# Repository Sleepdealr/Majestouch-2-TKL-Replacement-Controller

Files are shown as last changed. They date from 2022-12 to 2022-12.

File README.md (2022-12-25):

# Majestouch 2 TKL Replacement Controller

This board has been prototyped. It is tested and working

Kicad source files are provided, as well as QMK firmware with Vial support

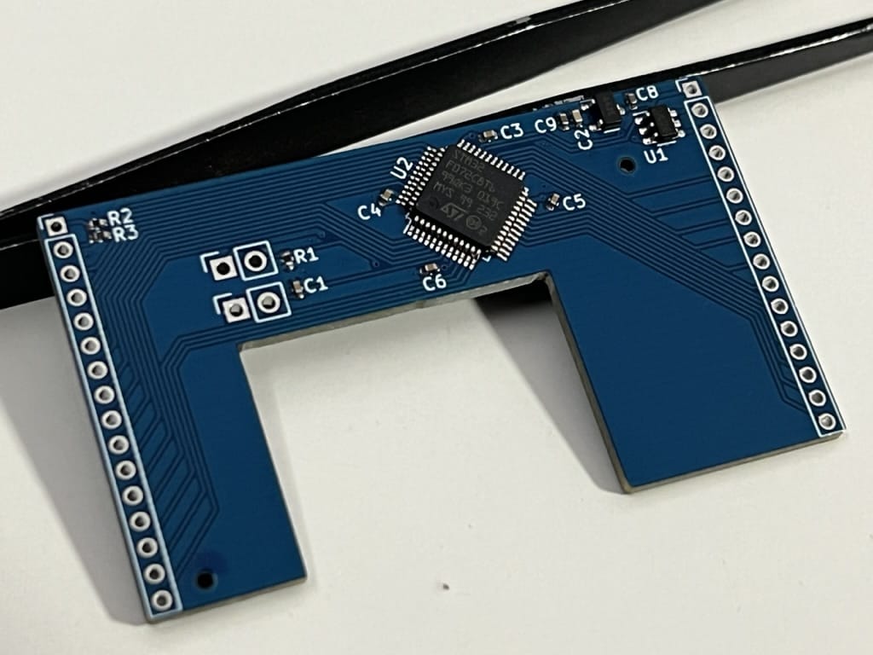
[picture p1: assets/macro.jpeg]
Macro Photo

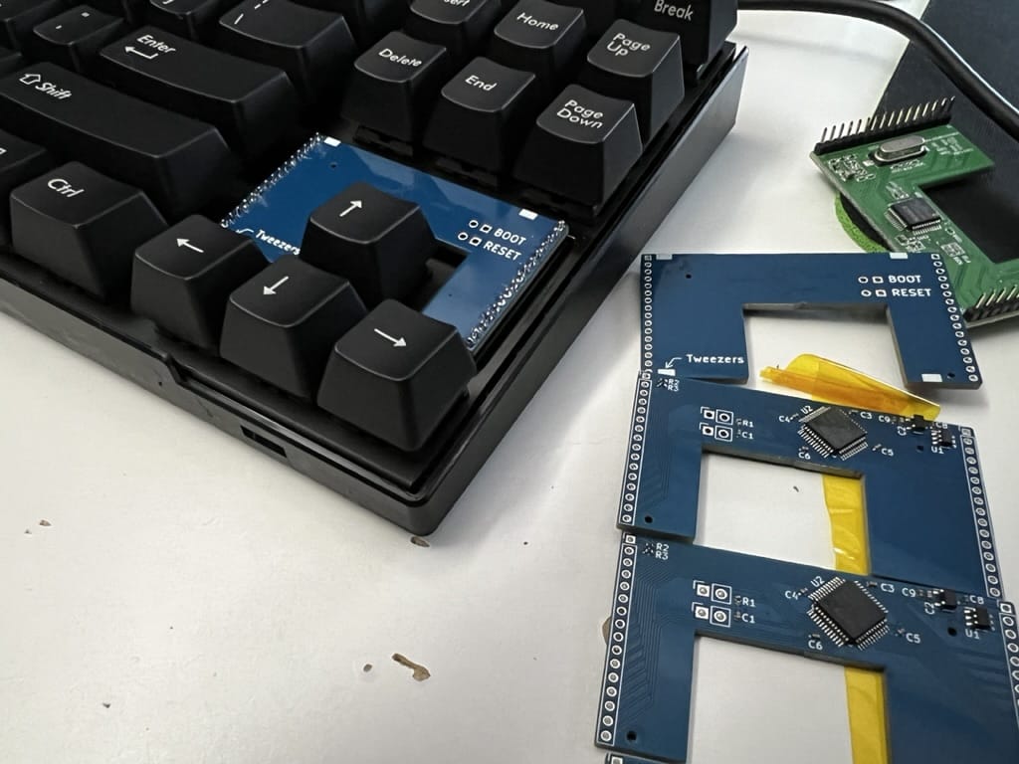
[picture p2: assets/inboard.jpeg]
In Board


## Resources Used

- Matrix: <https://deskthority.net/wiki/Controller_matrix_traces#Filco_Majestouch_TKL>
- Outline: <https://github.com/Tecsmith/flying-horse-foot/>
  - Used calipers to double check with physical model

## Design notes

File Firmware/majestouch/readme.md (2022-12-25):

# Majestouch 2 TKL Replacement Controller

Replacement controller for the Majestouch 2 TKL

* Keyboard Maintainer: [Sleepdealer](https://github.com/Sleepdealr)
* Hardware Supported: Majestouch 2 TKL
* Hardware Availability: Amazon or whatever

Make example for this keyboard (after setting up your build environment):

    make sleepdealer/majestouch:default

Flashing example for this keyboard:

    make sleepdealer/majestouch:default:flash

See the [build environment setup](https://docs.qmk.fm/#/getting_started_build_tools) and the [make instructions](https://docs.qmk.fm/#/getting_started_make_guide) for more information. Brand new to QMK? Start with our [Complete Newbs Guide](https://docs.qmk.fm/#/newbs).

## Bootloader

Enter the bootloader in 3 ways:

* **Bootmagic reset**: Hold down the key at (0,0) in the matrix (usually the top left key or Escape) and plug in the keyboard
* **Physical reset button**: Briefly press the button on the back of the PCB - some may have pads you must short instead
* **Keycode in layout**: Press the key mapped to `RESET` if it is available

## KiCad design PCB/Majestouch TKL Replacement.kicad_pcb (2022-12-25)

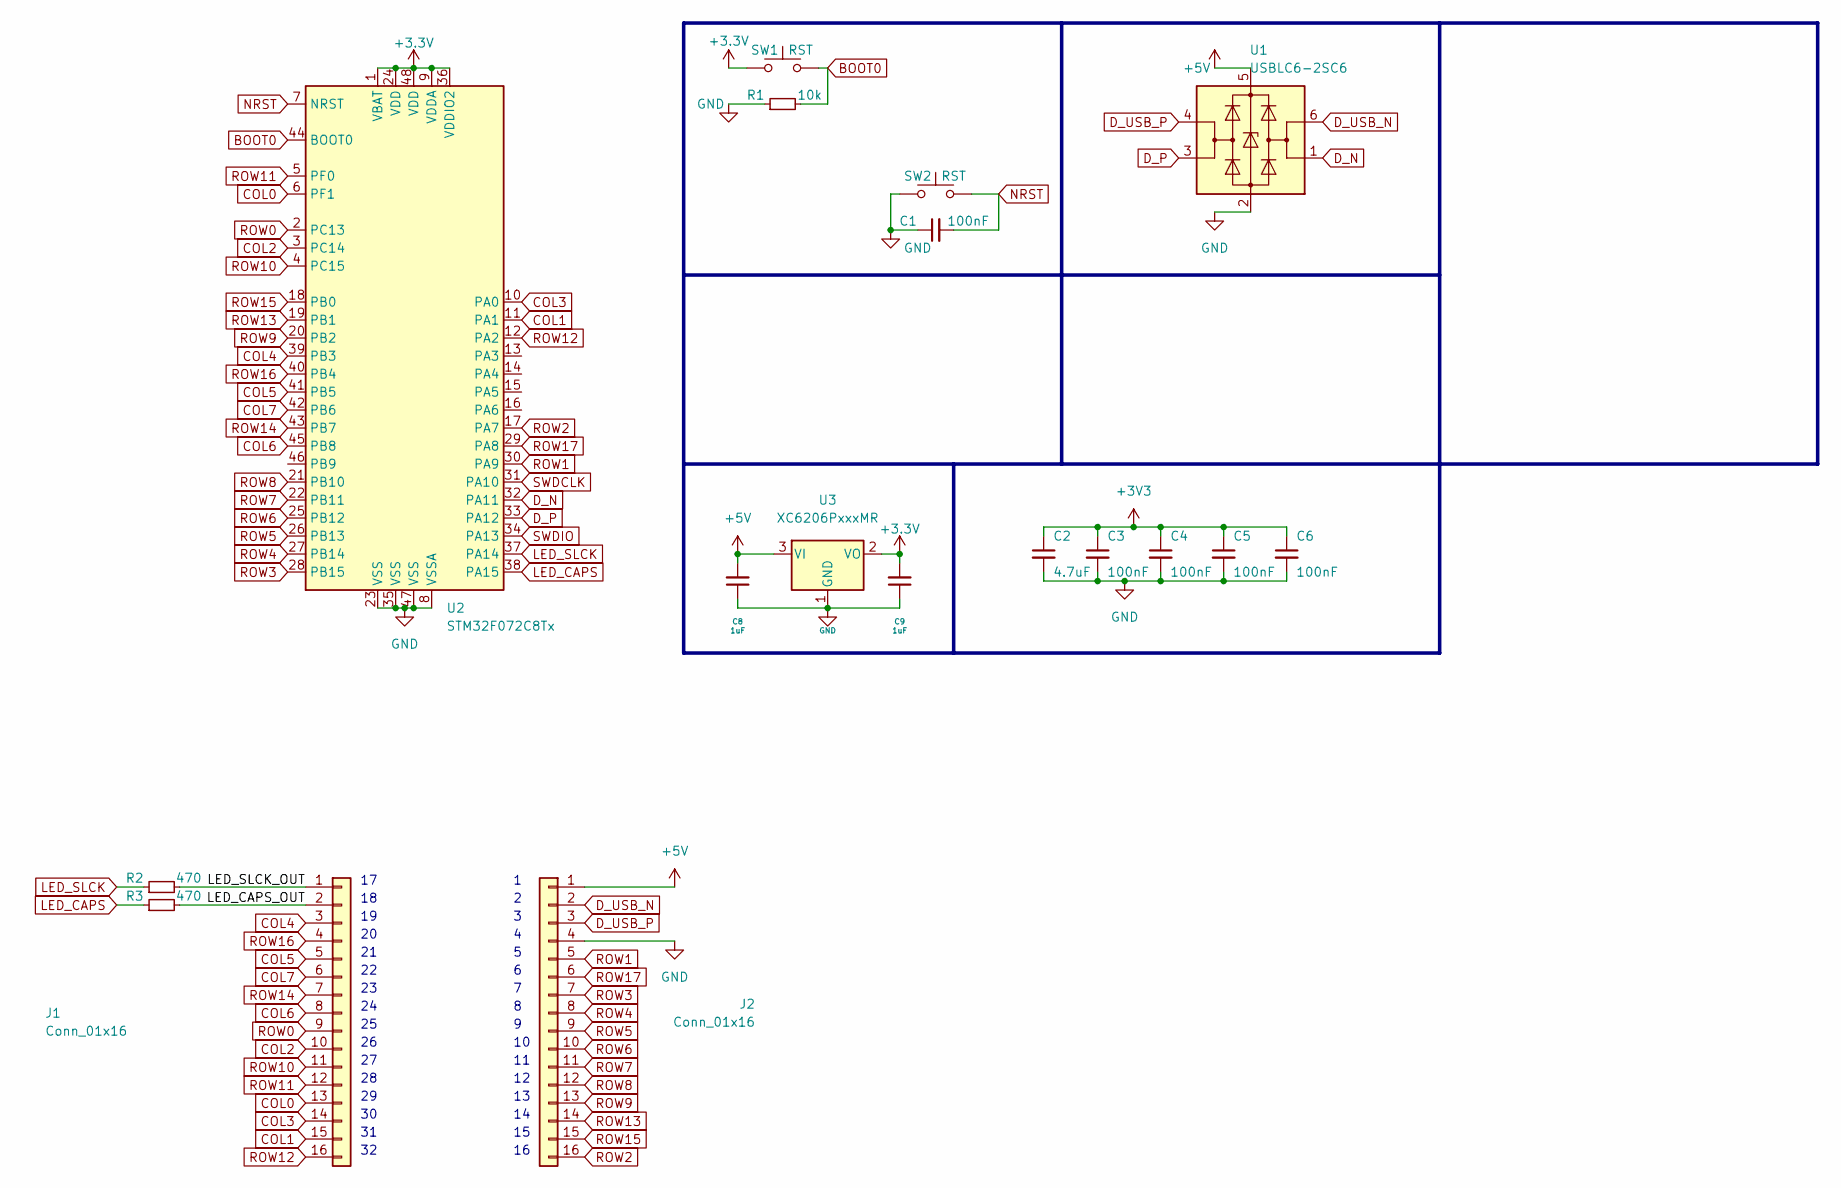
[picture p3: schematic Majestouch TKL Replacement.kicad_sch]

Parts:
C1, C3, C4, C5, C6: 100nF; C_0402_1005Metric; LCSC C307331
C2: 4.7uF; C_0402_1005Metric; LCSC C52923
C8, C9: 1uF; C_0402_1005Metric; LCSC C52923
J1, J2: Conn_01x16; PinHeader_1x16_P2.00mm_Vertical
R1: 10k; R_0402_1005Metric
R2, R3: 470; R_0402_1005Metric
SW1, SW2: RST; PinSocket_1x02_P2.54mm_Vertical
U1: USBLC6-2SC6; SOT-23-6
U2: STM32F072C8Tx; LQFP-48_7x7mm_P0.5mm
U3: XC6206PxxxMR; SOT-23

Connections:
+5V: C8.2, J2.1, U1.5 (VBUS), U3.3 (VI)
/LED_CAPS_OUT: J1.2, R3.2
/LED_SLCK_OUT: J1.1, R2.2
BOOT0: R1.2, SW1.2, U2.44 (BOOT0)
COL0: J1.13, U2.6 (PF1)
COL1: J1.15, U2.11 (PA1)
COL2: J1.10, U2.3 (PC14)
COL3: J1.14, U2.10 (PA0)
COL4: J1.3, U2.39 (PB3)
COL5: J1.5, U2.41 (PB5)
COL6: J1.8, U2.45 (PB8)
COL7: J1.6, U2.42 (PB6)
D_N: U1.1 (I/O1), U2.32 (PA11)
D_P: U1.3 (I/O2), U2.33 (PA12)
D_USB_N: J2.2, U1.6 (I/O1)
D_USB_P: J2.3, U1.4 (I/O2)
GND: C1.1, C2.2, C3.2, C4.2, C5.2, C6.2, C8.1, C9.1, J2.4, R1.1, SW2.1, U1.2 (GND), U2.8 (VSSA), U2.23 (VSS), U2.35 (VSS), U2.47 (VSS), U3.1 (GND)
LED_CAPS: R3.1, U2.38 (PA15)
LED_SLCK: R2.1, U2.37 (PA14)
NRST: C1.2, SW2.2, U2.7 (NRST)
ROW0: J1.9, U2.2 (PC13)
ROW1: J2.5, U2.30 (PA9)
ROW2: J2.16, U2.17 (PA7)
ROW3: J2.7, U2.28 (PB15)
ROW4: J2.8, U2.27 (PB14)
ROW5: J2.9, U2.26 (PB13)
ROW6: J2.10, U2.25 (PB12)
ROW7: J2.11, U2.22 (PB11)
ROW8: J2.12, U2.21 (PB10)
ROW9: J2.13, U2.20 (PB2)
ROW10: J1.11, U2.4 (PC15)
ROW11: J1.12, U2.5 (PF0)
ROW12: J1.16, U2.12 (PA2)
ROW13: J2.14, U2.19 (PB1)
ROW14: J1.7, U2.43 (PB7)
ROW15: J2.15, U2.18 (PB0)
ROW16: J1.4, U2.40 (PB4)
ROW17: J2.6, U2.29 (PA8)
SWDCLK: U2.31 (PA10)
SWDIO: U2.34 (PA13)

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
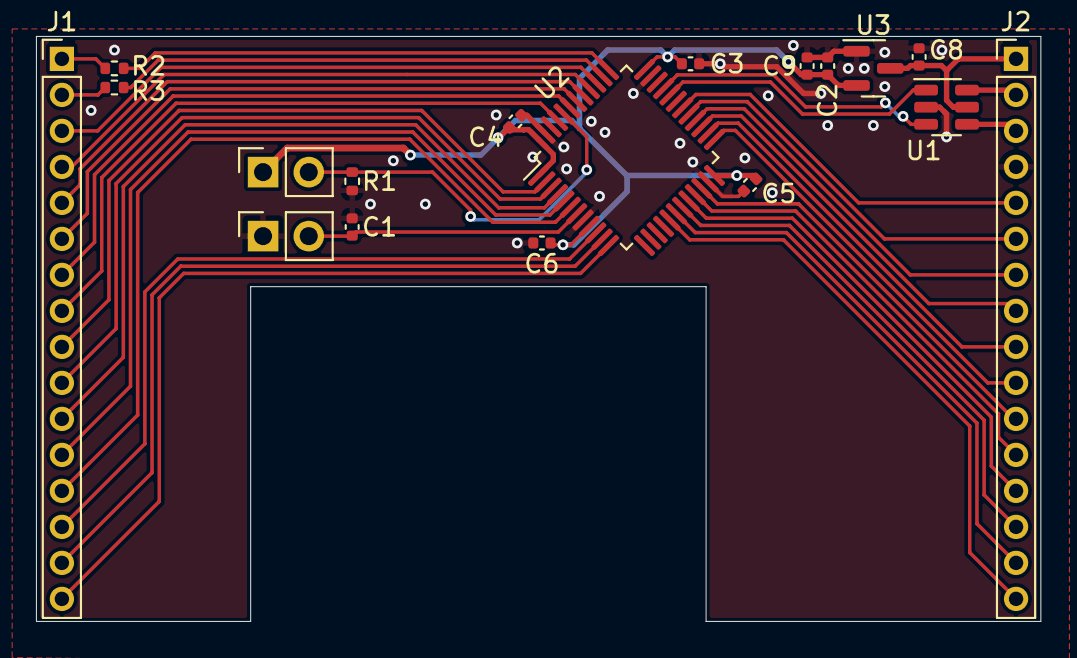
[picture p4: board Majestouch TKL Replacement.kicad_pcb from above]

Board: 2 copper layers, 55.8 x 32.5 mm, 18 parts (0 on the bottom side), 39 nets.
